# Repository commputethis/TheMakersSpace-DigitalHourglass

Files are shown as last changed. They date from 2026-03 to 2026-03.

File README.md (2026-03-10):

# The Maker's Space Digital Hourglass - ESP32 Dual TFT Hourglass Clock

A digital hourglass clock built on an ESP32, featuring two circular TFT screens that display a sand animation synchronized to the current time. The project includes a full web configuration interface for setting the timer mode, NTP server, timezone, daylight saving time, and a full suite of color options, with all settings stored persistently in EEPROM.

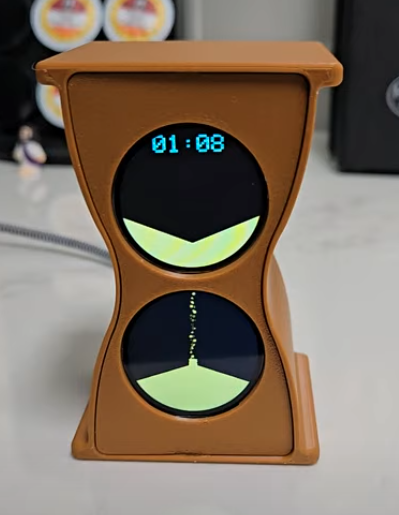
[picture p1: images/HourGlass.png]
Image of the final project


---

## Table of Contents

1.  [Features](#features)
2.  [Hardware Required](#hardware-required)
3.  [Wiring Diagram](#wiring-diagram)
4.  [Software Setup](#software-setup)
5.  [Configuration](#configuration)
6.  [How It Works](#how-it-works)
7.  [Troubleshooting](#troubleshooting)
8.  [Attributions](#attributions)

---

## Features

-   **Dual TFT Displays:** Uses two 240x240 circular GC9A01A TFT displays to show the upper and lower "bulbs" of the hourglass.
-   **Accurate Timekeeping:** Keeps time using a DS3231 Real-Time Clock (RTC) module, synchronized via NTP over WiFi.
-   **Two Timer Modes:**
    -   **Minute Mode:** The sand animation completes one full cycle every minute.
    -   **Hour Mode:** The sand animation completes one full cycle every hour.
-   **Web Configuration:** A built-in web server allows you to configure all settings without reprogramming the device:
    -   Toggle between Minute and Hour mode.
    -   Toggle between 12-hour and 24-hour time format.
    -   Select your timezone from a named dropdown list of 45 worldwide timezones.
    -   Toggle automatic Daylight Saving Time (DST) adjustment on or off.
    -   Set the NTP server.
    -   Customize the colors of the clock text, background, and sand.
    -   Reset WiFi credentials without losing other settings.
    -   Perform a full factory reset to restore all defaults.
-   **Persistent Settings:** All configuration is saved to the ESP32's EEPROM, so your settings are preserved after a power cycle.
-   **WiFiManager with Unique SSID:** For easy initial WiFi setup. The ESP32 creates a unique access point for each board (e.g., `Hourglass-A4CF12...`) to prevent confusion in multi-device environments like classrooms.

---

## Hardware Required

| Component | Quantity | Notes |
|---|---|---|
| [ESP32 DevKit V1](https://www.amazon.com/dp/B0C7C2HQ7P) | 1 | The "brains" of the project. |
| [1.28" GC9A01A Circular TFT (240x240)](https://www.amazon.com/Teyleten-Robot-Display-Interface-240x240/dp/B0B7TFRNN1) | 2 | For the upper and lower glass displays. |
| [DS3231 Real-Time Clock (RTC) Module](https://www.amazon.com/dp/B08X4H3NBR) | 1 | For accurate timekeeping. |
| [Female to Male Jumper Wires](https://www.amazon.com/dp/B07GD1R5MS) | 14 | For power, ground, SDA, and SCL connections. |
| [Female to Female Jumper Wires](https://www.amazon.com/dp/B07GD312VG) | 6 | For DC, CS, and RST connections. |
| [Male to Male Jumper Wires](https://www.amazon.com/dp/B07GD1ZCHQ) | 2 | For power and ground connection on RTC. |
| [221-413 Wago Lever Nuts](https://www.amazon.com/dp/B0957T1S9C) | 2 | For TFT SDA and SCL connections. |
| [221-415 Wago Lever Nuts](https://www.amazon.com/dp/B0957T1S9C) | 2 | For Power and Ground connections. |
| 5V Power Supply | 1 | Ensure it can provide enough current for both displays (at least 500mA is recommended). |
| [3D Printed Case](files/3D_Models) | 1 | Hourglass looking enclosure to house the components. |

---

## Wiring Diagram

The following table shows the correct pin assignments for the ESP32 DevKit V1. **Double-check your specific board's pinout diagram**, as "D" numbers can vary. The GPIO number is the most reliable reference. Note: pins below are for the ESP32 DevKit V1 used in this project.

> **Note on TFT pin labels:** Many GC9A01A display modules label their SPI pins as `SDA` (for MOSI) and `SCL` (for SCK). This is a common labeling convention on breakout boards. These connect to the ESP32's standard SPI pins as shown below.

| Device Pin | Connect to ESP32 Pin | Typical "D" Number | Notes |
|---|---|---|---|
| **SPI Bus (Shared)** | | | |
| TFT SDA (SPI MOSI) | `GPIO 23` | `D23` | Connect to 221-413 Wago Lever Nut using Female to Male Jumper Wire. |
| TFT SCL (SPI SCK) | `GPIO 18` | `D18` | Connect to 221-413 Wago Lever Nut using Female to Male Jumper Wire. |
| **TFT 1 (Upper Glass)** | | | |
| CS (Chip Select) | `GPIO 2` | `D2` | Using Female to Female Jumper Wire. |
| DC (Data/Command) | `GPIO 5` | `D5` | Using Female to Female Jumper Wire. |
| RST (Reset) | `GPIO 4` | `D4` | Using Female to Female Jumper Wire. |
| VCC | `3.3V` | `3V3` | Connect to 221-415 Wago Lever Nut using Female to Male Jumper Wire. |
| GND | `GND` | `GND` | Connect to 221-415 Wago Lever Nut using Female to Male Jumper Wire. |
| **TFT 2 (Lower Glass)** | | | |
| CS (Chip Select) | `GPIO 19` | `D19` | Using Female to Female Jumper Wire. |
| DC (Data/Command) | `GPIO 17` | `TX2` | Using Female to Female Jumper Wire. |
| RST (Reset) | `GPIO 15` | `D15` | Using Female to Female Jumper Wire. |
| VCC | `3.3V` | `3V3` | Connect to 221-415 Wago Lever Nut using Female to Male Jumper Wire. |
| GND | `GND` | `GND` | Connect to 221-415 Wago Lever Nut using Female to Male Jumper Wire. |
| **RTC Module (DS3231)** | | | |
| SDA (I2C Data) | `GPIO 21` | `D21` | Using Female to Male Jumper Wire. |
| SCL (I2C Clock) | `GPIO 22` | `D22` | Using Female to Male Jumper Wire. |
| VCC | `3.3V` | `3V3` | Connect to 221-415 Wago Lever Nut using Male to Male Jumper Wire. |
| GND | `GND` | `GND` | Connect to 221-415 Wago Lever Nut using Male to Male Jumper Wire. |

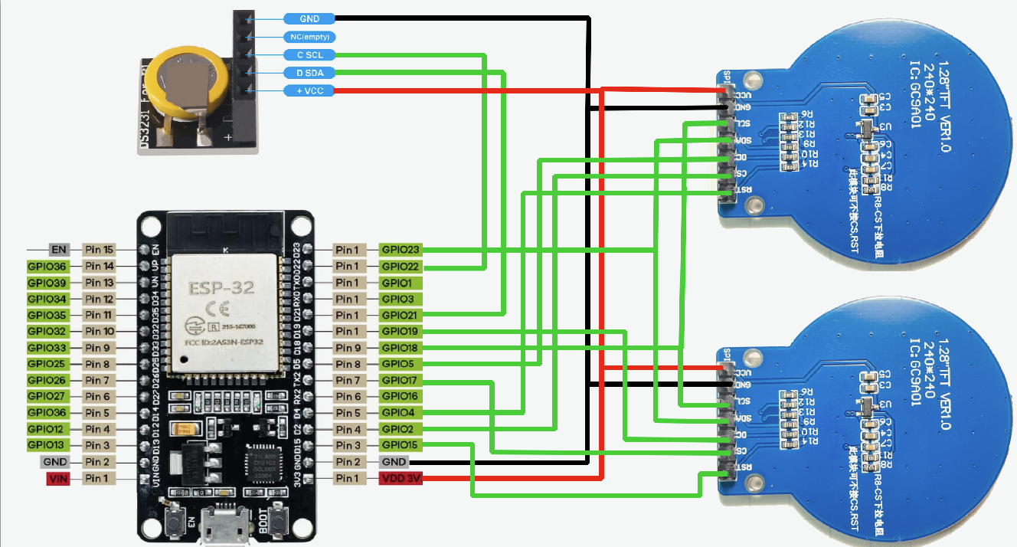
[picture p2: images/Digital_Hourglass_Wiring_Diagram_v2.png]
Wiring Diagram


---

## Software Setup

### 1. Prerequisites

-   **Arduino IDE:** Ensure you have the latest version installed.
-   **ESP32 Board Manager:** In Arduino IDE, go to `File > Preferences`. Add this URL to "Additional Board Manager URLs":
    ```
    https://raw.githubusercontent.com/espressif/arduino-esp32/gh-pages/package_esp32_index.json
    ```
    Then, go to `Tools > Board > Boards Manager...`, search for "esp32", and install the package.

### 2. Install Required Libraries

Go to `Tools > Manage Libraries...` and install the following libraries:

-   `Adafruit GFX Library`
-   `Adafruit GC9A01A`
-   `RTClib by Adafruit`
-   `WiFiManager by tzapu`
-   `NTPClient by Fabrice Weinberg`
-   `ArduinoJson by Benoit Blanchon` (Required by WiFiManager)

### 3. Load the Code

The project is split into two files.

1.  **Create the Main Sketch (`.ino`):**
    -   Create a new sketch in the Arduino IDE.
    -   Copy the entire [HourGlass.ino](/files/HourGlass/HourGlass.ino) code and paste it into this sketch.
2.  **Create the Color Header File (`colors.h`):**
    -   In the Arduino IDE, click the down-arrow button on the far right of the tabs and select "New Tab".
    -   Name the new tab `colors.h`.
    -   Copy the entire content of the [colors.h](/files/HourGlass/colors.h) file and paste it into this new tab.
3.  **Upload:**
    -   Select your ESP32 board from `Tools > Board > ESP32 Arduino > ESP32 Dev Module`.
    -   Connect your ESP32 to your computer and select the correct COM port.
    -   Click "Upload".

> **Note for users upgrading from a previous version:** The EEPROM configuration format has been updated. On first boot after uploading, the device will not find a valid saved configuration and will revert to defaults. You will need to reconfigure your settings once via the web interface. This is expected behavior.

---

## Configuration

### First-Time WiFi Setup

1.  Power on the device.
2.  The upper TFT will display "WiFi..." and the **unique SSID for that specific board** (e.g., `Hourglass-A4CF12C8D6E4`).
3.  On your phone or computer, scan for WiFi networks and connect to the SSID shown on the screen.
4.  A captive portal should open automatically. If not, navigate to `192.168.4.1`.
5.  Select your WiFi network and enter the password.
6.  The ESP32 will connect, and the hourglass will start.

### Web Configuration Interface

Once the ESP32 is connected to your network, you can access the configuration page at any time.

1.  Find the ESP32's IP address from the Arduino Serial Monitor.
2.  Open a web browser and navigate to that IP address (e.g., `http://192.168.1.123`).
3.  You will see the status page showing all current settings. Click the **Configure** button.
4.  On the configuration page, you can:
    -   **Timer Mode:** Switch between `Minute Mode` and `Hour Mode`.
    -   **Time Format:** Switch between `12-Hour` and `24-Hour` format.
    -   **Timezone:** Select your local timezone from a dropdown list of 45 named worldwide timezones.
    -   **Daylight Saving Time:** Enable or disable automatic DST adjustment. When enabled, the device automatically applies the correct DST rule for your selected timezone (US/Canada, EU/UK, or Southern Hemisphere).
    -   **NTP Server:** Change the server used for time synchronization (e.g., `pool.ntp.org`).
    -   **Clock Color:** Choose the color for the time display on the upper screen.
    -   **Background Color:** Choose the background color for both screens.
    -   **Sand Color:** Choose the color of the animated sand.
5.  Click **Save & Restart**. The device will reboot with the new settings.

### Danger Zone

The bottom of the configuration page contains two reset options, each with a confirmation step to prevent accidental use.

-   **Reset WiFi Credentials:** Clears only the saved WiFi network and password. All other settings (timezone, colors, mode, etc.) are preserved. The device will restart and create its setup hotspot so you can connect to a new network.
-   **Factory Reset:** Clears **all** saved settings including WiFi credentials, timezone, colors, and all other configuration. The device will restart in first-time setup mode. **This action cannot be undone.**

---

## How It Works

-   **Time Source:** The ESP32 first tries to get the time from an NTP server. If successful, it sets the DS3231 RTC. If NTP fails, it falls back to the time compiled into the sketch. The RTC ensures the device keeps accurate time even if WiFi is lost.
-   **Timezone & DST:** The timezone is stored as an index into a built-in table of 45 named worldwide timezones. Each entry includes its standard UTC offset, DST offset, and DST rule type (US/Canada, EU/UK, Southern Hemisphere, or no DST). The `getEffectiveOffset()` function calculates the correct UTC offset at any given moment, automatically switching between standard and DST time when enabled.
-   **Time Format:** The `drawTimeDisplay()` function checks the `configIs24Hour` setting. If true, it displays the hour in 24-hour format (e.g., `14:00`). If false, it displays the hour in 12-hour format (e.g., `2:00`).
-   **Unique ID:** The device generates a unique ID from its MAC address. This ID is used to create a unique WiFi SSID (`Hourglass-` + ID) for the initial setup portal, making it easy to identify individual devices in a classroom.
-   **Color Customization:** The `colors.h` file defines a palette of 14 colors as raw 16-bit RGB565 hex values. The web interface lets you select an index from this palette for the clock, background, and sand. These choices are saved to EEPROM and applied at startup.
-   **Animation:** The `drawFrame()` function calculates how far through the current minute or hour the device is. It then draws the corresponding amount of sand in the upper and lower bulbs using an incremental update system that avoids full screen redraws on every frame.
-   **Sand Stream:** The `drawSandStream()` function creates the illusion of flowing sand by drawing and erasing small circles in the center column. A carefully sized clear lane prevents ghosting or artifact pixels from persisting between frames.
-   **Web Server:** A lightweight web server runs in the background on port 80, allowing you to change settings without interrupting the main animation loop.
-   **NTP Re-sync:** The device re-syncs with the NTP server every 24 hours to correct any RTC drift, then recalculates the animation start position to stay in sync with the actual time.

---

## Troubleshooting

-   **Displays are blank or white:**
    -   Check all wiring, especially `3.3V`, `GND`, `CS`, and `DC`.
    -   Ensure your 5V power supply can provide enough current (at least 500mA is recommended).
    -   Make sure you have installed the `Adafruit_GC9A01A` library.
-   **WiFi doesn't connect:**
    -   On first boot, it will create a unique access point (e.g., `Hourglass-A4CF12...`). **Look at the upper TFT screen to see the exact SSID.** Connect to that to configure WiFi.
    -   Double-check your WiFi password in the portal.
    -   If you need to connect to a new network, use the **Reset WiFi Credentials** option in the web configuration Danger Zone.
-   **Time is incorrect:**
    -   Check the NTP server setting in the web config. `time.google.com` is a reliable default.
    -   Ensure you have selected the correct timezone from the dropdown list.
    -   If your time is off by exactly one hour, check that the **Daylight Saving Time** setting is correct for your region and time of year.
-   **Time reverted to defaults after an update:**
    -   This is expected when upgrading from a previous version of the firmware. The EEPROM format was updated. Reconfigure your settings once via the web interface and they will be saved correctly going forward.
-   **Code won't compile:**
    -   Make sure you have installed all the required libraries listed in the Software Setup section.
    -   Ensure you have created the `colors.h` tab and pasted the color definitions into it. The name must match exactly.

---

## Attributions

- This was originally created by Markus Opitz and published on [Instructables](https://www.instructables.com/Digital-Hourglass/).
- The [3D case](/files/3D_Models/) was redesigned by Don Potbury.

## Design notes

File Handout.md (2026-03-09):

# The Maker's Space - March 9th, 2026

### **Build a Digital Hourglass!**

**A modern take on a classic timepiece using an ESP32, dual TFT screens, and web-based configuration.**

---

#### **What You'll Build**

A functional hourglass that:
-   Shows a mesmerizing sand animation synced to the current time.
-   Runs in **Minute Mode** (1 min/cycle) or **Hour Mode** (1 hr/cycle).
-   Displays time in **12-hour** or **24-hour** format.
-   Connects to WiFi for automatic timekeeping.
-   Is fully customizable via a simple web interface on your phone or computer.

---

#### **Core Components**

| Component | Role |
|---|---|
| **ESP32 DevKit V1** | The "brain" that runs the code, animation, and web server. |
| **(2x) GC9A01A TFT Displays** | The "eyes" that show the upper and lower bulbs of the hourglass. |
| **DS3231 RTC Module** | The "heartbeat" that keeps perfect time, even without WiFi. |
| **Jumper Wires & Power** | Connects everything and provides power. |

---

#### **The Build Process (At a Glance)**

1.  **Wire It Up:** Connect the components to the ESP32 following the wiring diagram. Pay close attention to the `CS`, `DC`, and `RST` pins for each display.
2.  **Load the Code:** Install the required libraries in the Arduino IDE and upload the provided `HourGlass.ino` and `colors.h` files.
3.  **Configure WiFi:** On first boot, the ESP32 creates its own WiFi network (e.g., `Hourglass-A4CF12...`). Connect to it with your phone to set up your home WiFi.
4.  **Customize!** Once connected to your network, find the device's IP address in the Arduino Serial Monitor. Open it in a browser to access the configuration page. Here you can:
    -   Set your timezone and enable/disable Daylight Saving Time.
    -   Choose your preferred time format.
    -   Pick custom colors for the clock, background, and sand.
    -   Switch between Minute and Hour modes.

---

#### **Key Features to Explore**

-   **Web Configuration:** No reprogramming needed! Change all settings from a simple web page.
-   **45+ Timezones:** Select your location from a named list. The device handles the rest.
-   **Automatic DST:** When enabled, it automatically adjusts for Daylight Saving Time based on your timezone's rules.
-   **Factory Reset:** A built-in option to wipe all settings and start fresh.

---

#### **Need Help?**

All the details you need are in the project's GitHub repository, including:
-   Full wiring diagram
-   Complete source code
-   Troubleshooting guide
-   3D models for the case

**Visit:**

**`https://github.com/commputethis/TheMakersSpace-DigitalHourglass`**

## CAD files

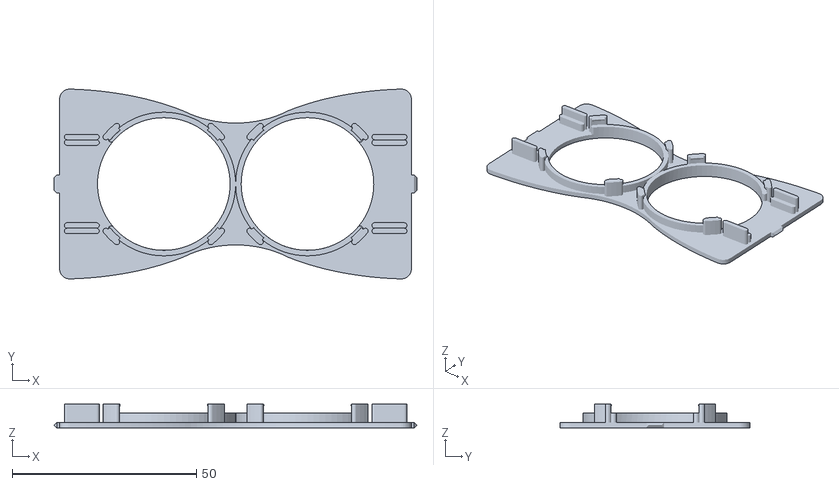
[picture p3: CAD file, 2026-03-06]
files/3D_Models/Digital_Hourglass_Remix_Front.stl
98.5 x 51.5 x 6.50

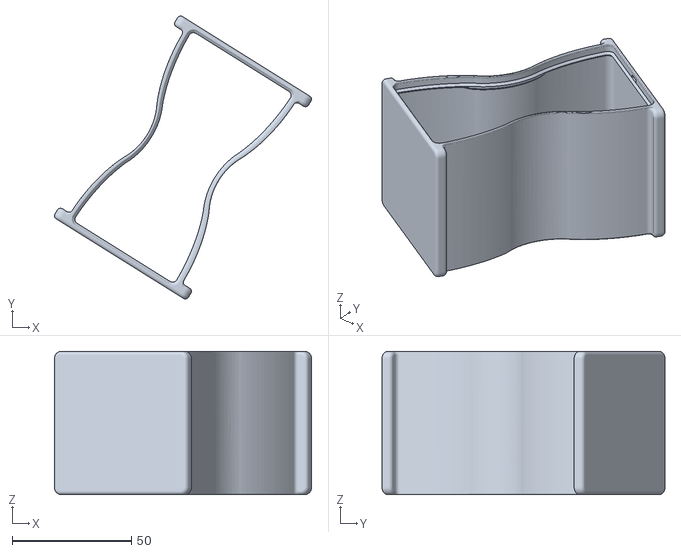
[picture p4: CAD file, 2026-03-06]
files/3D_Models/Digital_Hourglass_Remix_Body.stl
107.8 x 118.6 x 60.0

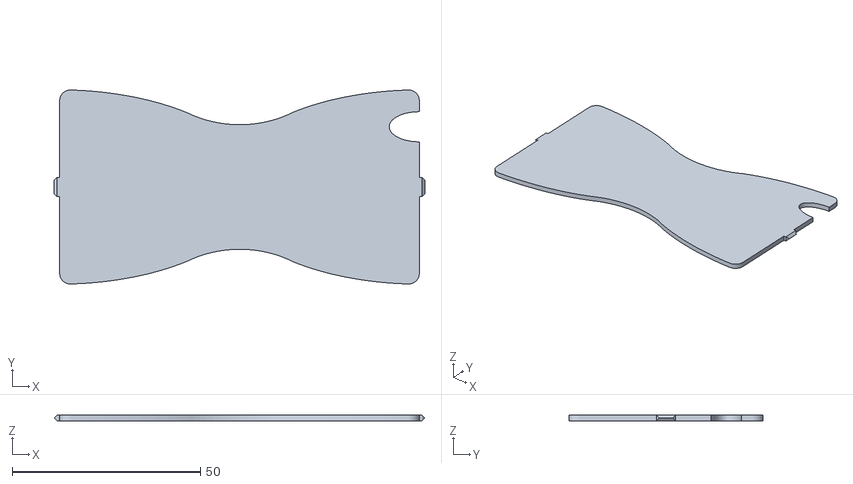
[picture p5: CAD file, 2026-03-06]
files/3D_Models/Digital_Hourglass_Remix_Back.stl
98.5 x 51.5 x 1.50

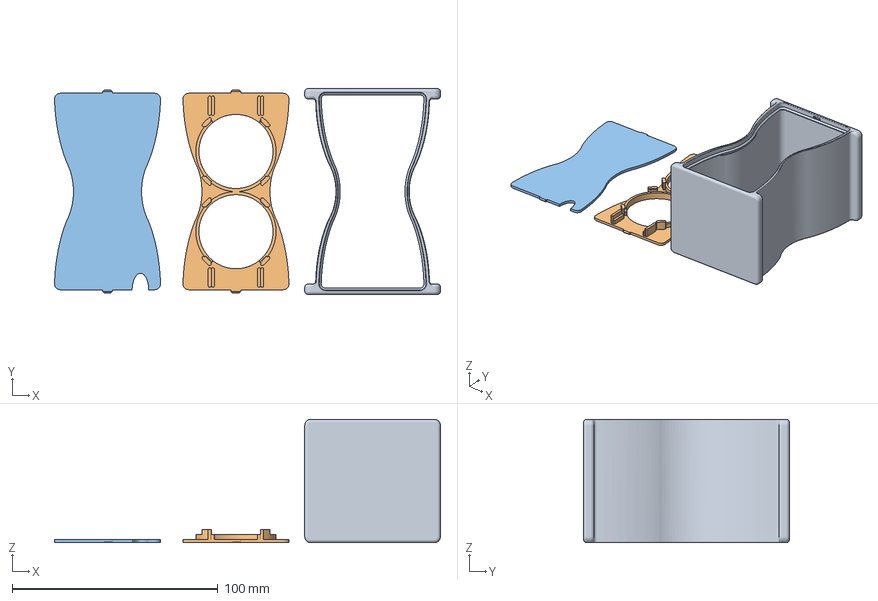
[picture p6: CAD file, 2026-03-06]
files/3D_Models/Digital_Hourglass_Remix.3mf
187.6 x 100.0 x 60.0 mm
Enclosure.stl
Front.stl
Back.stl

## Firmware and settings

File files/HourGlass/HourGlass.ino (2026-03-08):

// HourGlass.ino — ESP32 with DST, Extended Timezones, Factory/WiFi Reset
#include "Adafruit_GFX.h"
#include "Adafruit_GC9A01A.h"
#include "colors.h"
#include <EEPROM.h>
#include <RTClib.h>
#include <WiFi.h>
#include <WiFiManager.h>
#include <WebServer.h>
#include <NTPClient.h>
#include <WiFiUdp.h>
#include <time.h>

// ===== TIMER MODE =====
bool HOUR_MODE = false;

// ===== PIN DEFINITIONS =====
#define TFT1_DC   5
#define TFT1_CS   2
#define TFT1_RST  4
#define TFT2_DC   17
#define TFT2_CS   19
#define TFT2_RST  15

#define RTC_SET_FLAG_ADDR  0
#define NTP_SYNC_TIME_ADDR 1
#define CONFIG_VALID_ADDR  6
#define CONFIG_VALID_BYTE  0xAC  // Changed from 0xAB — forces clean reset on first load

// EEPROM layout:
//   100     : HOUR_MODE (0 or 1)
//   101-164 : NTP server string (64 bytes)
//   165     : Timezone index (uint8_t)   <-- replaces old int32_t offset
//   166     : DST enabled (uint8_t)      <-- NEW
//   167-168 : reserved
//   169     : Clock Color Index (uint8_t)
//   170     : Background Color Index (uint8_t)
//   171     : Sand Color Index (uint8_t)
//   172     : 24-Hour Mode (uint8_t)

// ===== STREAM GEOMETRY CONSTANTS =====
#define STREAM_CX           120
#define STREAM_X_HALF         7
#define STREAM_X_MIN        (STREAM_CX - STREAM_X_HALF)
#define STREAM_X_MAX        (STREAM_CX + STREAM_X_HALF)
#define STREAM_CLEAR_MARGIN   3
#define STREAM_CLEAR_X      (STREAM_X_MIN - STREAM_CLEAR_MARGIN)
#define STREAM_CLEAR_W      (STREAM_X_MAX - STREAM_X_MIN + 1 + 2 * STREAM_CLEAR_MARGIN)

// ============================================================
//  TIMEZONE TABLE
//  DST Rules:
//    0 = No DST
//    1 = US/Canada  (2nd Sun Mar 2AM  — 1st Sun Nov 2AM)
//    2 = EU/UK      (last Sun Mar 2AM — last Sun Oct 2AM)
//    3 = S.Hemisphere (1st Sun Oct 2AM — 1st Sun Apr 2AM)
// ============================================================
struct TimezoneEntry {
  const char* name;
  int standardOffset; // minutes from UTC
  int dstOffset;      // additional minutes during DST (usually 60)
  int dstRule;
};

const TimezoneEntry timezones[] = {
  {"(UTC-12:00) Baker Island",              -720,  0, 0},
  {"(UTC-11:00) Pago Pago (SST)",           -660,  0, 0},
  {"(UTC-10:00) Honolulu (HST)",            -600,  0, 0},
  {"(UTC-09:00) Anchorage (AKST)",          -540, 60, 1},
  {"(UTC-08:00) Los Angeles (PST)",         -480, 60, 1},
  {"(UTC-07:00) Denver (MST)",              -420, 60, 1},
  {"(UTC-07:00) Phoenix (MST / no DST)",    -420,  0, 0},
  {"(UTC-06:00) Chicago (CST)",             -360, 60, 1},
  {"(UTC-05:00) New York (EST)",            -300, 60, 1},  // index 8 = DEFAULT
  {"(UTC-04:00) Halifax (AST)",             -240, 60, 1},
  {"(UTC-03:30) St. Johns (NST)",           -210, 60, 1},
  {"(UTC-03:00) Sao Paulo (BRT)",           -180,  0, 0},
  {"(UTC-03:00) Buenos Aires (ART)",        -180,  0, 0},
  {"(UTC-02:00) South Georgia",             -120,  0, 0},
  {"(UTC-01:00) Azores (AZOT)",              -60, 60, 2},
  {"(UTC+00:00) London (GMT)",                 0, 60, 2},
  {"(UTC+00:00) Reykjavik (GMT/no DST)",       0,  0, 0},
  {"(UTC+01:00) Paris / Berlin (CET)",        60, 60, 2},
  {"(UTC+01:00) Lagos (WAT/no DST)",          60,  0, 0},
  {"(UTC+02:00) Athens / Helsinki (EET)",    120, 60, 2},
  {"(UTC+02:00) Cairo (EET / no DST)",       120,  0, 0},
  {"(UTC+02:00) Johannesburg (SAST)",        120,  0, 0},
  {"(UTC+02:00) Harare (CAT)",               120,  0, 0},
  {"(UTC+03:00) Moscow (MSK)",               180,  0, 0},
  {"(UTC+03:00) Riyadh / Nairobi",           180,  0, 0},
  {"(UTC+03:30) Tehran (IRST/no DST)",       210,  0, 0},
  {"(UTC+04:00) Dubai / Baku (GST)",         240,  0, 0},
  {"(UTC+04:30) Kabul (AFT)",                270,  0, 0},
  {"(UTC+05:00) Karachi (PKT)",              300,  0, 0},
  {"(UTC+05:30) Mumbai / Delhi (IST)",       330,  0, 0},
  {"(UTC+05:45) Kathmandu (NPT)",            345,  0, 0},
  {"(UTC+06:00) Dhaka (BST)",                360,  0, 0},
  {"(UTC+06:30) Yangon (MMT)",               390,  0, 0},
  {"(UTC+07:00) Bangkok (ICT)",              420,  0, 0},
  {"(UTC+08:00) Beijing / Singapore (CST)",  480,  0, 0},
  {"(UTC+08:00) Perth (AWST / no DST)",      480,  0, 0},
  {"(UTC+09:00) Tokyo (JST)",                540,  0, 0},
  {"(UTC+09:00) Seoul (KST)",                540,  0, 0},
  {"(UTC+09:30) Adelaide (ACST)",            570, 60, 3},
  {"(UTC+10:00) Sydney / Melbourne (AEST)",  600, 60, 3},
  {"(UTC+10:00) Brisbane (AEST / no DST)",   600,  0, 0},
  {"(UTC+11:00) Noumea (NCT)",               660,  0, 0},
  {"(UTC+12:00) Auckland (NZST)",            720, 60, 3},
  {"(UTC+12:00) Fiji (FJT / no DST)",        720,  0, 0},
  {"(UTC+13:00) Apia (WST)",                 780,  0, 0},
};
const uint8_t TIMEZONE_COUNT = sizeof(timezones) / sizeof(timezones[0]);

// ===== DYNAMIC COLOR VARIABLES =====
uint16_t clockColor;
uint16_t bgColor;
uint16_t sandColor;

// ===== DISPLAY OBJECTS =====
Adafruit_GC9A01A tft1(TFT1_CS, TFT1_DC, TFT1_RST);
Adafruit_GC9A01A tft2(TFT2_CS, TFT2_DC, TFT2_RST);

// ===== RTC =====
RTC_DS3231 rtc;

// ===== WiFi / NTP / Web server =====
WiFiUDP       ntpUDP;
NTPClient     timeClient(ntpUDP, "time.google.com", 0, 60000);
WebServer     server(80);
bool          ntpSynced    = false;
unsigned long lastSyncTime = 0;
const unsigned long syncInterval = 86400000UL;

// ===== CONFIGURATION =====
bool    configHourMode        = false;
char    configNtpServer[64]   = "time.google.com";
uint8_t configTimezoneIndex   = 8;     // Default: New York (EST)
bool    configDstEnabled      = true;  // Default: DST on
uint8_t configClockColorIndex = 6;     // Default: Cyan
uint8_t configBgColorIndex    = 0;     // Default: Black
uint8_t configSandColorIndex  = 12;    // Default: Sand
bool    configIs24Hour        = false; // Default: 12-hour

// ===== ANIMATION STATE =====
const int     totalFrames          = 141;
int           m                    = 0;
int           n                    = 0;
unsigned long animationStartMillis = 0;
int           lastMinuteTracked    = -1;
bool          needsFullRedraw      = true;
bool          needsTimeUpdate      = false;
unsigned long lastStreamUpdate     = 0;
int           streamOffset         = 0;

// ===== CURRENT LOCAL TIME =====
int currentMinute = 0;
int currentHour   = 0;
int hour12        = 0;

// ===== WiFiManager portal-save flag =====
bool portalConfigSaved = false;
void onPortalSave() { portalConfigSaved = true; }

// ============================================================
//  HELPER: Unique device ID from MAC address
// ============================================================
String getDeviceId() {
  uint64_t chipid = ESP.getEfuseMac();
  char id[12];
  snprintf(id, sizeof(id), "%04X%08X",
    (uint32_t)(chipid >> 32), (uint32_t)(chipid & 0xFFFFFFFF));
  return String(id);
}

// ============================================================
//  DST HELPERS
// ============================================================

// Day of week (0=Sunday ... 6=Saturday) — Tomohiko Sakamoto algorithm
int dayOfWeek(int year, int month, int day) {
  static const int t[] = {0,3,2,5,0,3,5,1,4,6,2,4};
  if (month < 3) year--;
  return (year + year/4 - year/100 + year/400 + t[month-1] + day) % 7;
}

// Day number of the nth weekday in a given month
// weekday: 0=Sunday ... 6=Saturday
// nth: 1,2,3,4  or  -1 for last occurrence
int nthWeekdayOfMonth(int year, int month, int weekday, int nth) {
  int daysInMonth[] = {31,28,31,30,31,30,31,31,30,31,30,31};
  if (month == 2 && ((year%4==0 && year%100!=0) || year%400==0))
    daysInMonth[1] = 29;
  int firstDow = dayOfWeek(year, month, 1);
  int first    = 1 + ((weekday - firstDow + 7) % 7);
  if (nth == -1) {
    int last = first;
    while (last + 7 <= daysInMonth[month-1]) last += 7;
    return last;
  }
  return first + (nth - 1) * 7;
}

// Returns true if local STANDARD time falls within a DST period
bool isInDST_Rule(int year, int month, int day, int hour, int dstRule) {
  if (dstRule == 0) return false;
  const int H = 2; // transition hour (2:00 AM local standard time)

  if (dstRule == 1) { // US/Canada: 2nd Sun Mar — 1st Sun Nov
    int s = nthWeekdayOfMonth(year,  3, 0,  2);
    int e = nthWeekdayOfMonth(year, 11, 0,  1);
    if (month > 3 && month < 11) return true;
    if (month ==  3) return (day > s) || (day == s && hour >= H);
    if (month == 11) return (day < e) || (day == e && hour <  H);
    return false;
  }
  if (dstRule == 2) { // EU/UK: last Sun Mar — last Sun Oct
    int s = nthWeekdayOfMonth(year,  3, 0, -1);
    int e = nthWeekdayOfMonth(year, 10, 0, -1);
    if (month > 3 && month < 10) return true;
    if (month ==  3) return (day > s) || (day == s && hour >= H);
    if (month == 10) return (day < e) || (day == e && hour <  H);
    return false;
  }
  if (dstRule == 3) { // Southern Hemisphere: 1st Sun Oct — 1st Sun Apr
    int s = nthWeekdayOfMonth(year, 10, 0, 1);
    int e = nthWeekdayOfMonth(year,  4, 0, 1);
    if (month > 10 || month < 4) return true;
    if (month >= 5 && month <= 9) return false;
    if (month == 10) return (day > s) || (day == s && hour >= H);
    if (month ==  4) return (day < e) || (day == e && hour <  H);
    return false;
  }
  return false;
}

// Returns the effective UTC offset in minutes, DST-adjusted
int32_t getEffectiveOffset(time_t utcTime) {
  if (configTimezoneIndex >= TIMEZONE_COUNT) return -300;
  const TimezoneEntry& tz = timezones[configTimezoneIndex];
  int32_t offset = tz.standardOffset;
  if (configDstEnabled && tz.dstOffset > 0 && tz.dstRule != 0) {
    // Use local standard time to evaluate the DST boundary
    time_t stdLocal = utcTime + (int32_t)(offset * 60);
    DateTime sdt(stdLocal);
    if (isInDST_Rule(sdt.year(), sdt.month(), sdt.day(), sdt.hour(), tz.dstRule))
      offset += tz.dstOffset;
  }
  return offset;
}

// ===== FORWARD DECLARATIONS =====
void drawFrame(int frame);
void drawSandStream(int bottomY);
void drawTimeDisplay();
void saveConfig();
void loadConfig();
void setupWiFi();
void startWebServer();
void syncRTCwithNTP();
void applyColors();

// ============================================================
//  SETUP
// ============================================================
void setup() {
  Serial.begin(115200);
  delay(2000);

  EEPROM.begin(512);
  loadConfig();
  applyColors();

  tft1.begin(); tft2.begin();
  tft1.setRotation(2); tft2.setRotation(0);
  tft1.fillScreen(bgColor);
  tft2.fillScreen(bgColor);

  if (!rtc.begin()) {
    Serial.println("RTC not found!");
    while (1) delay(10);
  }

  bool isFirstRun = (EEPROM.read(RTC_SET_FLAG_ADDR) != 1);

  setupWiFi();
  syncRTCwithNTP();

  if (isFirstRun && !ntpSynced) {
    Serial.println("NTP failed — using compile timestamp.");
    rtc.adjust(DateTime(F(__DATE__), F(__TIME__)));
  }
  if (isFirstRun) {
    EEPROM.write(RTC_SET_FLAG_ADDR, 1);
    EEPROM.commit();
  }

  randomSeed(analogRead(A0));

  time_t utc = rtc.now().unixtime();
  int32_t effOffset = getEffectiveOffset(utc);
  time_t local = utc + (effOffset * 60);
  DateTime localTime(local);

  currentMinute     = localTime.minute();
  hour12            = localTime.hour();
  currentHour       = (hour12 == 0) ? 12 : ((hour12 > 12) ? hour12 - 12 : hour12);
  lastMinuteTracked = currentMinute;

  int secondsIn = HOUR_MODE
    ? (localTime.minute() * 60 + localTime.second())
    : localTime.second();
  animationStartMillis = millis() - (secondsIn * 1000UL);

  bool dstNow = configDstEnabled && (effOffset != timezones[configTimezoneIndex].standardOffset);
  Serial.printf("TZ: %s  Offset: %d min  DST: %s  Time: %02d:%02d:%02d  Mode: %s  Fmt: %s\n",
    timezones[configTimezoneIndex].name, effOffset,
    dstNow ? "ACTIVE" : "inactive",
    localTime.hour(), localTime.minute(), localTime.second(),
    HOUR_MODE ? "HOUR" : "MIN",
    configIs24Hour ? "24hr" : "12hr");
}

// ============================================================
//  WiFi SETUP
// ============================================================
void setupWiFi() {
  portalConfigSaved = false;
  WiFi.mode(WIFI_STA);

  WiFiManager wifiManager;
  wifiManager.setSaveConfigCallback(onPortalSave);
  wifiManager.setConfigPortalTimeout(180);

  char modeStr[2]; snprintf(modeStr, sizeof(modeStr), "%d", configHourMode ? 1 : 0);
  char tzStr[4];   snprintf(tzStr,   sizeof(tzStr),   "%d", configTimezoneIndex);
  char dstStr[2];  snprintf(dstStr,  sizeof(dstStr),  "%d", configDstEnabled ? 1 : 0);
  char clkStr[3];  snprintf(clkStr,  sizeof(clkStr),  "%d", configClockColorIndex);
  char bgStr[3];   snprintf(bgStr,   sizeof(bgStr),   "%d", configBgColorIndex);
  char sandStr[3]; snprintf(sandStr, sizeof(sandStr), "%d", configSandColorIndex);
  char fmtStr[2];  snprintf(fmtStr,  sizeof(fmtStr),  "%d", configIs24Hour ? 1 : 0);

  WiFiManagerParameter paramNtp  ("ntp",  "NTP Server",              configNtpServer, 64);
  WiFiManagerParameter paramMode ("mode", "Timer (0=Min 1=Hr)",      modeStr,          2);
  WiFiManagerParameter paramTz   ("tz",   "Timezone Index (0-44)",   tzStr,            4);
  WiFiManagerParameter paramDst  ("dst",  "DST (0=Off 1=On)",        dstStr,           2);
  WiFiManagerParameter paramClk  ("clk",  "Clock Color (0-13)",      clkStr,           3);
  WiFiManagerParameter paramBg   ("bg",   "BG Color (0-13)",         bgStr,            3);
  WiFiManagerParameter paramSand ("sand", "Sand Color (0-13)",       sandStr,          3);
  WiFiManagerParameter paramFmt  ("fmt",  "Format (0=12hr 1=24hr)",  fmtStr,           2);

  wifiManager.addParameter(&paramNtp);
  wifiManager.addParameter(&paramMode);
  wifiManager.addParameter(&paramTz);
  wifiManager.addParameter(&paramDst);
  wifiManager.addParameter(&paramClk);
  wifiManager.addParameter(&paramBg);
  wifiManager.addParameter(&paramSand);
  wifiManager.addParameter(&paramFmt);

  tft1.fillRect(0, 55, 240, 90, bgColor);
  tft1.setTextColor(clockColor);
  tft1.setTextSize(2);
  tft1.setCursor(10, 65);
  tft1.print("WiFi...");
  tft1.setTextSize(1);
  tft1.setCursor(10, 90);
  tft1.print("SSID: Hourglass-");
  tft1.setCursor(10, 102);
  tft1.print(getDeviceId());

  String apName = "Hourglass-" + getDeviceId();
  if (!wifiManager.autoConnect(apName.c_str())) {
    Serial.println("WiFi connection failed.");
    tft1.fillRect(0, 55, 240, 90, bgColor);
    return;
  }

  Serial.print("WiFi connected. IP: ");
  Serial.println(WiFi.localIP());

  if (portalConfigSaved) {
    const char* v;
    v = paramNtp.getValue();
    if (strlen(v) > 0) { strncpy(configNtpServer, v, 63); configNtpServer[63] = '\0'; }

    v = paramMode.getValue();
    if (strlen(v) > 0) { configHourMode = (v[0] == '1'); HOUR_MODE = configHourMode; }

    v = paramTz.getValue();
    if (strlen(v) > 0) { uint8_t i = (uint8_t)atoi(v); if (i < TIMEZONE_COUNT) configTimezoneIndex = i; }

    v = paramDst.getValue();
    if (strlen(v) > 0) configDstEnabled = (v[0] == '1');

    v = paramClk.getValue();
    if (strlen(v) > 0) { uint8_t i = (uint8_t)atoi(v); if (i < COLOR_PALETTE_COUNT) configClockColorIndex = i; }

    v = paramBg.getValue();
    if (strlen(v) > 0) { uint8_t i = (uint8_t)atoi(v); if (i < COLOR_PALETTE_COUNT) configBgColorIndex = i; }

    v = paramSand.getValue();
    if (strlen(v) > 0) { uint8_t i = (uint8_t)atoi(v); if (i < COLOR_PALETTE_COUNT) configSandColorIndex = i; }

    v = paramFmt.getValue();
    if (strlen(v) > 0) configIs24Hour = (v[0] == '1');

    saveConfig();
    applyColors();
  }

  startWebServer();
  tft1.fillRect(0, 55, 240, 90, bgColor);
}
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
void loop() {
  server.handleClient();

  time_t utc = rtc.now().unixtime();
  int32_t effOffset = getEffectiveOffset(utc);
  time_t local = utc + (effOffset * 60);
  DateTime now(local);

  currentMinute = now.minute();
  hour12        = now.hour();
  currentHour   = (hour12 == 0) ? 12 : ((hour12 > 12) ? hour12 - 12 : hour12);

  if (currentMinute != lastMinuteTracked) {
    lastMinuteTracked = currentMinute;
    bool dstActive = configDstEnabled && (effOffset != timezones[configTimezoneIndex].standardOffset);
    Serial.printf("Tick: %02d:%02d  mode=%s  DST=%s\n",
      currentHour, currentMinute,
      HOUR_MODE ? "HOUR" : "MIN",
      dstActive ? "active" : "inactive");
    if (!HOUR_MODE) { animationStartMillis = millis(); needsFullRedraw = true; }
    else            { needsTimeUpdate = true; }
  }

  unsigned long elapsed          = millis() - animationStartMillis;
  unsigned long intervalDuration = HOUR_MODE ? 3600000UL : 60000UL;

  if (HOUR_MODE && elapsed >= intervalDuration) {
    animationStartMillis = millis(); elapsed = 0;
    needsFullRedraw = true;
    Serial.println("Hour complete — resetting animation.");
  }

  int currentFrame = (int)constrain(
    (long)(elapsed / (intervalDuration / totalFrames)),
    0L, (long)(totalFrames - 1));

  if (millis() - lastStreamUpdate >= (HOUR_MODE ? 400UL : 150UL)) {
    lastStreamUpdate = millis();
    streamOffset = (streamOffset + 12) % 240;
  }

  drawFrame(currentFrame);

  if (ntpSynced && millis() - lastSyncTime > syncInterval) {
    Serial.println("24h elapsed — re-syncing NTP...");
    if (WiFi.status() != WL_CONNECTED) {
      WiFi.reconnect();
      int w = 0;
      while (WiFi.status() != WL_CONNECTED && w < 20) { delay(500); w++; yield(); }
    }
    syncRTCwithNTP();
    time_t su = rtc.now().unixtime();
    int32_t so = getEffectiveOffset(su);
    time_t sl = su + (so * 60);
    DateTime slocal(sl);
    int secs = HOUR_MODE ? (slocal.minute() * 60 + slocal.second()) : slocal.second();
    animationStartMillis = millis() - (secs * 1000UL);
    needsFullRedraw = true;
  }

  yield();
  delay(50);
}

// ============================================================
//  DRAW TIME DIGITS ONLY
// ============================================================
void drawTimeDisplay() {
  tft1.fillRect(55, 0, 185, 55, bgColor);
  tft1.setCursor(60, 15);
  tft1.setTextColor(clockColor);
  tft1.setTextSize(4);
  int displayHour = configIs24Hour ? hour12 : currentHour;
  if (displayHour < 10) tft1.print("0");
  tft1.print(displayHour);
  tft1.print(":");
  if (currentMinute < 10) tft1.print("0");
  tft1.print(currentMinute);
  needsTimeUpdate = false;
}

// ============================================================
//  DRAW FRAME
// ============================================================
void drawFrame(int frame) {
  static int lastFrame = -1;
  bool doFullRedraw = needsFullRedraw || (lastFrame == -1) || (abs(frame - lastFrame) > 5);

  if (doFullRedraw) {
    tft1.fillScreen(bgColor); tft2.fillScreen(bgColor);
    drawTimeDisplay();
    if (frame > 0) {
      m = frame;
      int upperY   = (int)(m * 0.9f + 68);
      int upperTip = (int)(m * 1.2f + 90);
      tft1.fillRect(0, upperY, 240, 240 - upperY, sandColor);
      tft1.fillTriangle(0, upperY, 240, upperY, 120, upperTip, bgColor);
      n = map(m, 0, totalFrames, 250, 75);
      int lowerY = (int)(n * 0.55f + 105);
      if (lowerY < 240) {
        tft2.fillTriangle(0, lowerY-1, 240, lowerY-1, 120, n, sandColor);
        tft2.fillRect(0, lowerY-1, 240, 241-lowerY, sandColor);
      }
      drawSandStream(n);
    } else {
      tft1.fillRect(0, 100, 240, 140, sandColor);
    }
    needsFullRedraw = false; lastFrame = frame; yield(); return;
  }

  if (needsTimeUpdate) drawTimeDisplay();
  if (frame == lastFrame) {
    if (m > 0 && m < totalFrames - 1) drawSandStream(n);
    return;
  }

  m = frame;
  int upperY   = (int)(m * 0.9f + 68);
  int upperTip = (int)(m * 1.2f + 90);
  tft1.fillTriangle(0, upperY, 240, upperY, 120, upperTip, bgColor);
  n = map(m, 0, totalFrames, 250, 75);
  int lowerY = (int)(n * 0.55f + 105);
  if (lowerY < 240) {
    tft2.fillTriangle(0, lowerY-1, 240, lowerY-1, 120, n, sandColor);
    tft2.fillRect(0, lowerY-1, 240, 241-lowerY, sandColor);
  }
  if (m < totalFrames - 1) drawSandStream(n);
  lastFrame = frame; yield();
}

// ============================================================
//  DRAW SAND STREAM
// ============================================================
void drawSandStream(int bottomY) {
  int streamBottom = min(bottomY - 10, 240);
  if (streamBottom <= 0) return;
  tft2.fillRect(STREAM_CLEAR_X, 0, STREAM_CLEAR_W, streamBottom, bgColor);
  for (int i = 0; i < streamBottom; i += 8) {
    int pos = (i + streamOffset) % streamBottom;
    if (pos < 0 || pos >= streamBottom) continue;
    int xOff   = constrain((int)random(-4, 5), -(STREAM_X_HALF-2), (STREAM_X_HALF-2));
    int radius = (int)random(1, 3);
    int cx     = STREAM_CX + xOff;
    if (cx-radius >= STREAM_CLEAR_X && cx+radius < STREAM_CLEAR_X+STREAM_CLEAR_W)
      tft2.fillCircle(cx, pos, radius, sandColor);
    if (random(3) == 0) {
      int cx2 = constrain(cx+(int)random(-2,3), STREAM_CLEAR_X+1, STREAM_CLEAR_X+STREAM_CLEAR_W-2);
      int cy2 = pos + (int)random(-3, 4);
      if (cy2 >= 0 && cy2 < streamBottom)
        tft2.fillCircle(cx2, cy2, 1, sandColor);
    }
  }
  for (int i = 0; i < 5; i++) {
    int gy = bottomY + (int)random(-12, -2);
    int gx = STREAM_CX + (int)random(-5, 6);
    int gr = (int)random(1, 3);
    if (gy > 0 && gy < 240 && gx-gr >= STREAM_CLEAR_X && gx+gr < STREAM_CLEAR_X+STREAM_CLEAR_W)
      tft2.fillCircle(gx, gy, gr, sandColor);
  }
  for (int i = 0; i < 3; i++) {
    int dx = STREAM_CX + (int)random(-5, 6);
    int dy = (int)random(0, streamBottom);
    if (dx >= STREAM_CLEAR_X && dx < STREAM_CLEAR_X+STREAM_CLEAR_W)
      tft2.drawPixel(dx, dy, sandColor);
  }
}

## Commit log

2026-03-05 Revise README with detailed project information
    Updated project title and expanded project description in README. Added detailed sections on features, hardware requirements, wiring diagram, software setup, configuration, operation, and troubleshoo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
2026-03-06 Revise components and wiring instructions in README
    Updated wiring details and added new components to the README.
2026-03-06 Add product links to hardware requirements
    Updated hardware requirements with product links and clarified power supply specifications.
2026-03-06 Update pin assignments and troubleshooting notes in README
2026-03-06 Change 3D Printed Case link to directory
    Updated the link for the 3D Printed Case to a directory containing models.
2026-03-08 Update HourGlass.ino
    Added code for DST, button to clear config, button to clear wifi info, and added more timezones
2026-03-09 Update attribution for 3D case redesign
2026-03-09 Update link for 3D case redesign attribution
2026-03-09 Create Handout for Digital Hourglass Project
    Added a comprehensive guide for building a digital hourglass using an ESP32, including components, build process, and features.
2026-03-09 Include wiring diagram in README
    Added wiring diagram image to README.
2026-03-09 Rename Digital Hourglass Wiring Diagram v2.png to Digital_Hourglass_Wiring_Diagram_v2.png
